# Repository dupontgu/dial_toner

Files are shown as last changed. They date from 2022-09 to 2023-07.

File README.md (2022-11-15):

# The Dial Toner

## An Unnecessary Series of Hardware Color Pickers

### The Dial Toner (Basic)

- The original. [Available on Etsy!](https://www.etsy.com/listing/1327220837/the-dial-toner-a-tactile-mechanical)
- Find usage instructions [here](/basic).
- Dial in your color using the delightfully tactile hex switches.
- Built-in RGB LED's show the (approximate!) color you have selected in real time.
- Smash the button to send the color into your design software (or anywhere, the device acts as a keyboard).
- Can be configured to output Hex, RGB, CMYK, or HSL color.

#### Rev02 

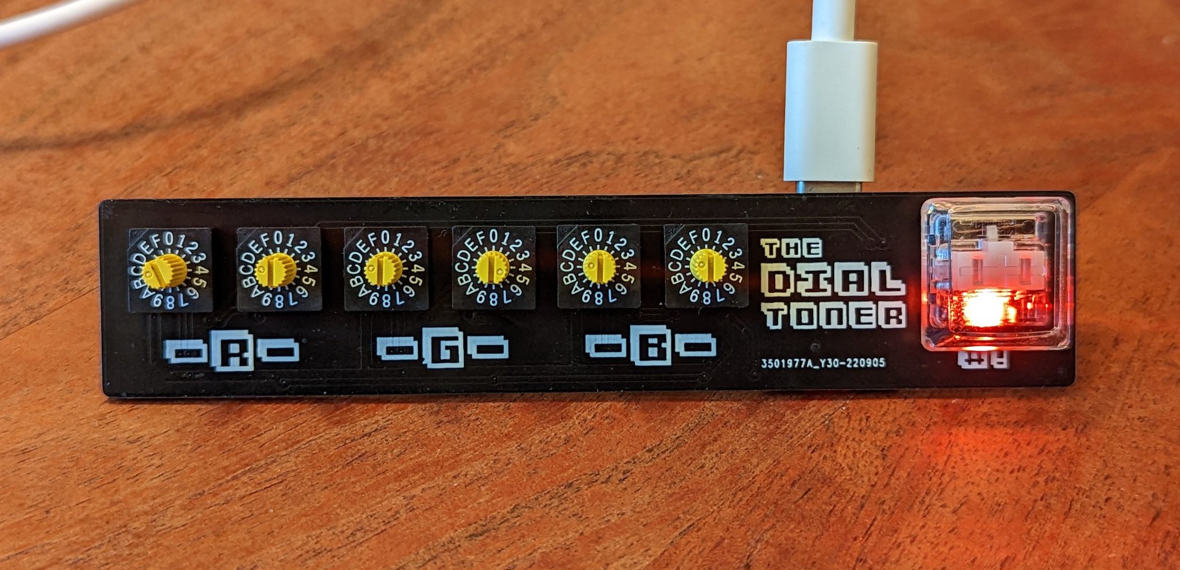
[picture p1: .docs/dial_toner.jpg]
Dial Toner Rev02 Board


----------

### The Dial Toner Ultra

- The "Swiss-army-knife".
- Find usage instructions [here](/ultra).
- Dial in your color using 4 analog dials. Input modes include Hex, RGB, CMYK, HSL, and P**tone.
- 1.3" LCD screen displays your color (and corresponding values) in real time.
- RGB backlit knobs because why not.
- Smash the button to send the color into your design software (or anywhere, the device acts as a keyboard).
- Can be configured to output Hex, RGB, CMYK, or HSL.

#### Rev01

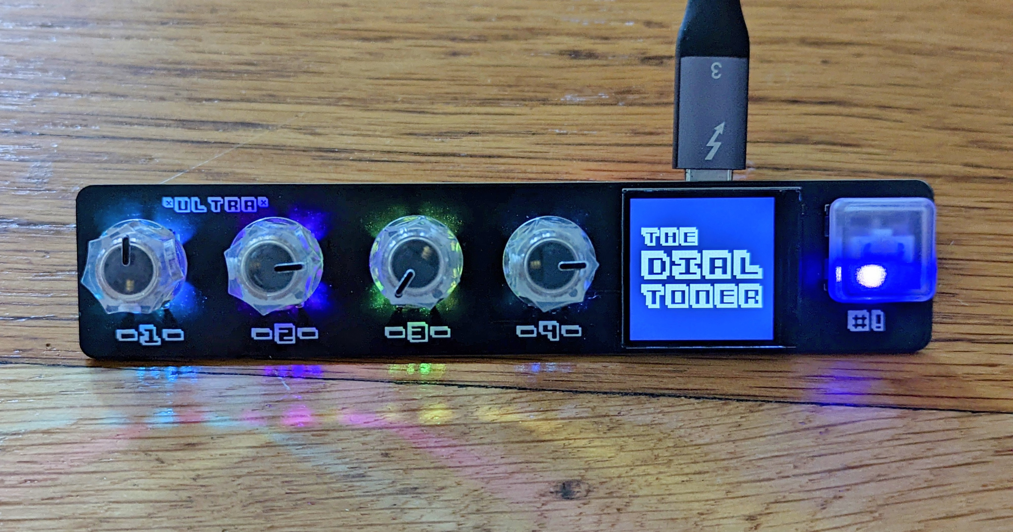
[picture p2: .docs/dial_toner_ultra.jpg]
Dial Toner Ultra Rev01 Board


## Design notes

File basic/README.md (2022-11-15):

# The Dial Toner (Basic)

Dial Toner Rev02 Board

## General Usage
1. Connect the Dial Toner to your computer via USB.
2. Dial in a hex color using the 6 knobs. (Note - the engraved line on top of the knob points to the selected value. There is a small circuilar impression on the _left_ sign of the line.)
3. Observe that the color of the LED (roughly) matches the color you have chosen.
4. Hit the button, and observe that the dial toner types your hex code (followed by a simulated enter key press).

## Changing Configuration
1. Unplug the device.
2. Hold down the “#!” button, and plug the device back in (keep holding!).
3. Hold until you see the LED come on - if it is fading through different colors, the device is in "config" mode. You can release the button.
4. In config mode, each of the knobs corresponds to a config parameter. When you change any of them the light will start to blink, indicating that a change has been made. Hit the button again to save your selection and resume normal operation.
    
    1. **The first knob changes the color output mode**. The possible values are 0 for a hex color string, 1 for RGB (integers, 0-255), 2 for CMYK percentages (decimals), 3 for HSL percentages (decimals). Any other value defaults to hex.

    1. **The second knob changes the "whitespace" mode**. The possible values are 0 for "space" (will insert a space between each discrete value), 1 for "tabs" (will insert a tab between each discrete value, 2 for "comma" (will insert "," between...). Any other value defaults to "space". Tabs are particularly useful when you want to fill multiple input fields in one go. Note - this setting does not affect hex color strings. 

    1. **The third knob sets whether or not to hit a simulated "enter" key after the color value is typed**. 0 will not append enter, 1 will append enter. Any other value defaults to 1 (append enter).

    1. **The fourth knob dials in LED brightness**. 0-F on the knob dials in the brightness percentage from ~0-80% (anything brighter is a bit much). Keep in mind - if you turn the brightness to 0, you will not see the light anymore! Probably a stupid feature, but somebody suggested that it might be fun to play a game where you pick a color and see how close you can dial it in without seeing it. 

    1. **The fifth knob changes the keyboard layout**. The possible values are 0 for United States English, 1 for British English (switches '#' and '£'), and 2 for "International" (should work for most other layouts). Any other selected value defaults to "US".

## Changing/Updating the Firmware:
- This device runs [CircuitPython](https://circuitpython.org/). It’s a really great way to get started with embedded software development. All of the code that powers this device is available on the device for you to play around with. 

- To change/update/check the firmware, you should boot up the device in Debug mode:
    1. Unplug the device
    2. Hold down the button, and plug the device back in (keep holding!).
    3. Wait until you see the LED come on and start cycling through colors (keep holding!).
    4. Unplug the device again.
    5. Keep holding the button down, plug in the device again.
    6. When the LED comes back on, the device should be in normal usage mode, but the storage drive should now be enabled! There should be a drive called CIRCUITPY mounted on your computer.

- To see which version of the firmware you are running, boot up in debug mode (described above), and check the file called `version.txt` on the CIRCUITPY drive. If there is no `version.txt` file, you are likely running version 0.0.1.

- "Official" firmware releases can be found [here](https://github.com/dupontgu/dial_toner/releases/). Find the latest release, and follow the link to the release's artifacts. Download the `DT Basic Bundle` zip file. Extract all of the files from the zip archive and copy them onto the CIRCUITPY drive. **Replace all existing files**. Once copying has finished the device will reboot and will be running the updated code.

- If you want the device to stay in Debug mode, so the files are available every time you reboot (without holding the button down):
    1. Boot the device in Debug mode as described above.
    1. Locate the file called ‘boot.py’ on the CIRCUITPY drive.
    1. Open it in a text editor. (If you don’t have a coding-oriented text editor installed, use something lightweight like TextEdit or Notepad. It’s best not to use a document editor like Microsoft Word)
    1. Change the line that says “DEBUG = False” to say “DEBUG = True”.
    1. Save the boot.py file.
    1. Reboot the device - it should stay in Debug mode as long as “DEBUG = True”.

- You can [change the name](https://learn.adafruit.com/welcome-to-circuitpython/renaming-circuitpy) of the `CIRCUITPY` drive if you want to.

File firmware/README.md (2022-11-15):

# CircuitPython firmware for The Dial Toner
- **This directory contains the code for all models of The Dial Toner**. Shared code lives in the [common](./circuitpython/common/) directory. Other directories contain hardware model-specific code. The [`bundle`](./circuitpython/bundle.py) script will create bundles for each model. The contents of each bundle can be loaded onto the corresponding device wholesale - all existing files should be overwritten. The bundle script also pulls in the necessary dependencies from Adafruit's CircuitPython library bundle.
- All code is currently written for CircuitPython 7. It has been tested on most 7.x releases since 7.2.5.
- All Dial Toner models are currently built around the [Seeeduino XIAO RP2040](https://www.seeedstudio.com/XIAO-RP2040-v1-0-p-5026.html) development board.

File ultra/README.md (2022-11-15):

# The Dial Toner (Ultra)

Dial Toner Ultra Rev01 Board

## General Usage
1. Connect the Dial Toner to your computer via USB.
2. Dial in a color using the 4 knobs. (Each knob will change a different characteristic of the color, depending on which input mode is currently selected. Only knobs with backlights on are active)
3. The text on the LCD screen will display the color's characteristics as you turn the knobs, and the background of the LCD will display the currently selected color.
4. Press and release the button, and observe that the Dial Toner types the selected color value on your computer.

------------

## Changing Configuration
1. To enter config mode, hold the button down for approxmiately 3 seconds. The lights on the board will start to blink once you are in config mode.
2. Once in config mode, the first two knobs can be used to change your settings. The first knob selects the config parameter to be changed. The second knob changes the value of the currently selected parameter.

### Config Parameters

1. **Input Mode, aka `MODE`** - Selects the input mode (colorspace) of the Dial Toner. This determines what each of the knobs does during normal operation.

    **Possible Values:**

    1. `HEX` - The knobs will be used to dial in a hexadecimal, 24-bit RGB color value. Knob 1 will adjust the `red` component, knob 2 will adjust the `green` component, knob 3 will adjust the `blue` component, and knob 4 will be inactive. Each component will be a discrete value between 0x00 and 0xFF. 

    1. `RGB` - The knobs will be used to dial in a 24-bit RGB color value. Knob 1 will adjust the `red` component, knob 2 will adjust the `green` component, knob 3 will adjust the `blue` component, and knob 4 will be inactive. Each component will be a discrete value between 0 and 255. (This is effectively the same as `HEX` mode - only the display is different).

    1. `CMYK` - The knobs will be used to dial in a CMYK color value. Knob 1 will adjust the `cyan` component, knob 2 will adjust the `magenta` component, knob 3 will adjust the `yellow` component, and knob 4 will adjust the `key` component. Each component will be a percentage between 0.0% and 100.0%.

    1. `P-TONE` - The knobs will be used to select a color ID from a certain, well-known ["color matching system"](https://www.pantone-colours.com/). Rhymes with schman-tone. Knob 1 will choose the thousand's digit (0,xxx - 9,xxx) of the ID, knob 2 will choose the hundred's digit (x,0xx - x,9xx), knob 3 will choose the tens's digit (x,x0x - x,x9x), and knob 4 will choose the one's digit (x,xx0, x,xx9). Note that not every number between 0-9999 is present, so the values might jump around a bit. 

    1. `HSL` - The knobs will be used to dial in n HSL. Knob 1 will adjust the `hue` component, knob 2 will adjust the `saturation` component, knob 3 will adjust the `lightness` component, and knob 4 will be inactive. The `hue` value will be an integer between 0 and 359. The `lightness` and `saturation` values will be percentages between 0.0% and 100%.

1. **Button LED Brightness, aka `BTN BRT`** - Adjusts the brightness of the RGB LEDs beneath the button and behind the board. Values are between 0% and 90%. Note that if you choose 0%, the LEDs will be off.

1. **Output Mode, aka `OUTPUT`** - Selects the output mode of the Dial Toner. This determines how the color will be typed out when you hit the button.

    **Possible Values:**

    1. `HEX` - The selected color will be typed out as a 6-digit hexadecimal RGB color, preceded by a `#` symbol. 
    For example: ```#FF4400```

    1. `RGB` - The selected color will be typed out as 3 discrete 8-bit integers. One for `red`, one for `green`, and one for `blue`. They will be separated by commas. 
    For example: ```255, 127, 0```

    1. `CMYK` - The selected color will be typed out as 4 floating point values between 0.0 and 1.0. The first for the `cyan` component, the second for `magenta`, the third for `yellow`, and the fourth for `key`. They will be separated by commas. 
    For example: ```0.334, 1.0, 0.5789229, 0.0```

    1. `HSL` - The selected color will be typed as 3 numbers: an integer (0-359) representing the `hue` component of the color, a floating point percentage value (0.0-1.0) representing the `saturation` level of the color, and another percentage representing the `lightness` of the color. They will be separated by commas.
    For example: ```255, 0.444, 1.0```

1. **Keyboard Layout aka `KEYBRD`** - Selects the regional keyboard layout that the Dial Toner will adhere to. It should match the keyboard layout that your computer is expecting. It ensures that the `#` key is typed correctly when the output mode is set to the `HEX`. The values are `US` for United States English, `UK` for British English, and `INTL` for everything else. (Forgive me for reducing everyone else to "international", but it seems like most other layouts treat the `#` the same way.)

1. **Append Key aka `APPEND`** - Determines whether or not the Dial Toner should append a key press when it is finished typing out a color value. Values are `ENTER` for a simulated `enter` (return) key press, and `NONE` for no additional key presses. Selecting `ENTER` might come in handy if you want to automatically _confirm_ a color selection in whatever software you're using.

---------

## Changing/Updating the Firmware:
- This device runs [CircuitPython](https://circuitpython.org/). It’s a really great way to get started with embedded software development. All of the code that powers this device is available on the device for you to play around with. 

- To change/update/check the firmware, you should boot up the device in Debug mode:
    1. Unplug the device
    2. Hold down the button, and plug the device back in (keep holding!).
    3. Wait until you see the LED come on and start cycling through colors (keep holding!).
    4. Unplug the device again.
    5. Keep holding the button down, plug in the device again.
    6. When the LED comes back on, the device should be in normal usage mode, but the storage drive should now be enabled! There should be a drive called CIRCUITPY mounted on your computer.

- To see which version of the firmware you are running, boot up in debug mode (described above), and check the file called `version.txt` on the CIRCUITPY drive. If there is no `version.txt` file, you are likely running version 0.0.1.

- "Official" firmware releases can be found [here](https://github.com/dupontgu/dial_toner/releases/). Find the latest release, and follow the link to the release's artifacts. Download the `DT Ultra Bundle` zip file. Extract all of the files from the zip archive and copy them onto the CIRCUITPY drive. **Replace all existing files**. Once copying has finished the device will reboot and will be running the updated code.

- If you want the device to stay in Debug mode, so the files are available every time you reboot (without holding the button down):
    1. Boot the device in Debug mode as described above.
    1. Locate the file called ‘boot.py’ on the CIRCUITPY drive.
    1. Open it in a text editor. (If you don’t have a coding-oriented text editor installed, use something lightweight like TextEdit or Notepad. It’s best not to use a document editor like Microsoft Word)
    1. Change the line that says “DEBUG = False” to say “DEBUG = True”.
    1. Save the boot.py file.
    1. Reboot the device - it should stay in Debug mode as long as “DEBUG = True”.

- You can [change the name](https://learn.adafruit.com/welcome-to-circuitpython/renaming-circuitpy) of the `CIRCUITPY` drive if you want to.

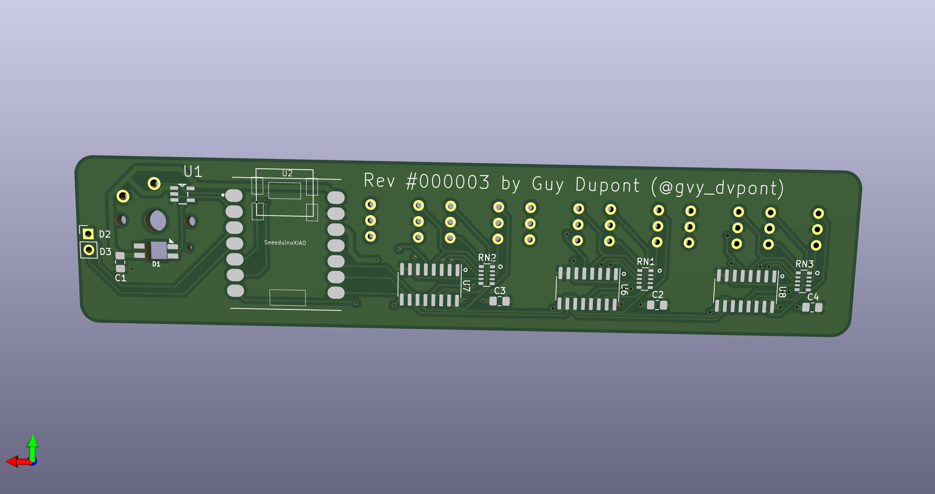
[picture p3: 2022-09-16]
hardware/rev03/dial_toner_mx_v2_back.jpg

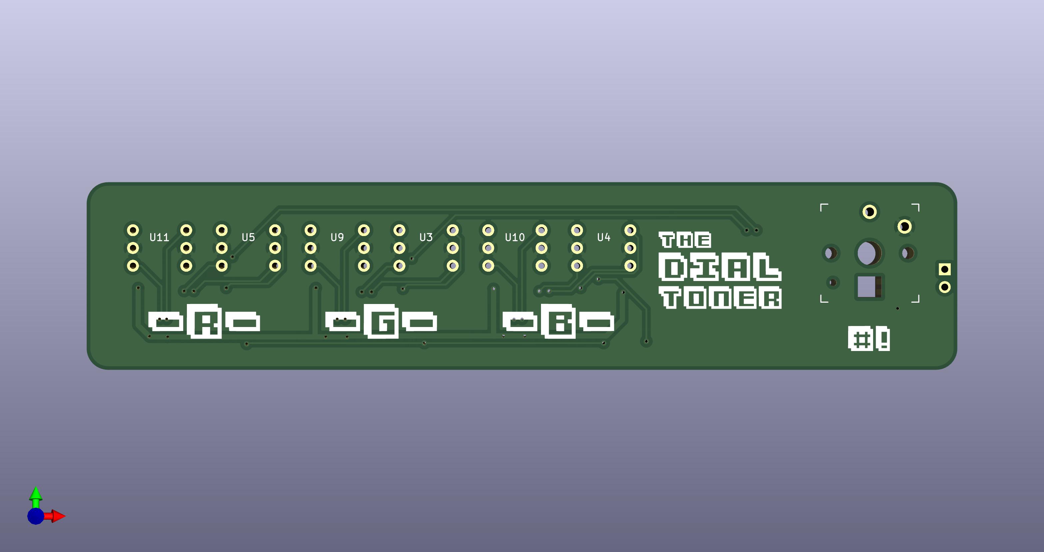
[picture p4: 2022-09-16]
hardware/rev03/dial_toner_mx_v2_front.jpg

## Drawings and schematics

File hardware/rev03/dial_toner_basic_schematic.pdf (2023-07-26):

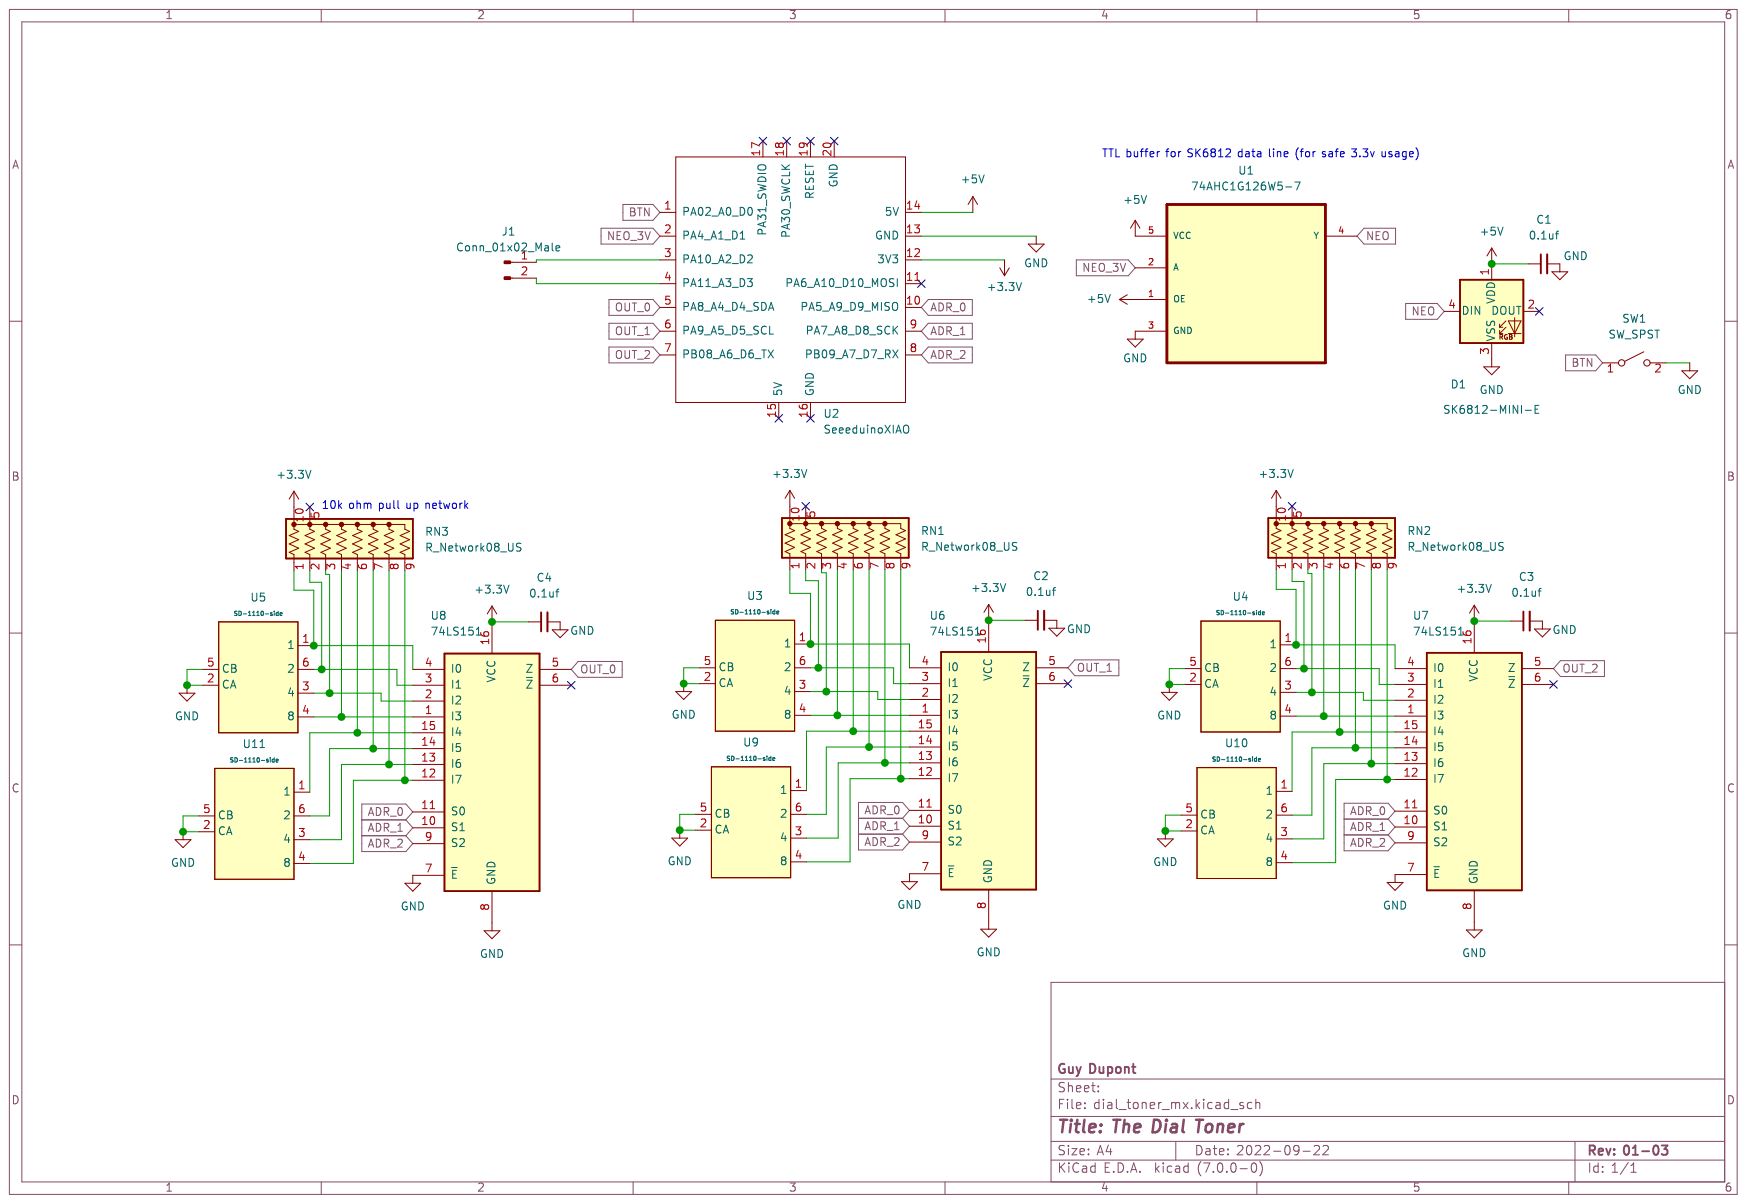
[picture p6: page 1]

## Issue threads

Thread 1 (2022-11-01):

Non-US keyboard - pound / hash symbol (#)

andypiper, 2022-11-01:
I'm using a v3 Dial Toner connected to macOS Ventura.

When I hit the button in the default hex mode, I'm getting (for example) `£E4512A` <- generated directly from the key pad right now.

The `£` symbol should be a `#` symbol 🙂

I'm not 100% sure how to fix this in the code.

On my keyboard, pressing the 3 key with Shift -> `£` and with Alt -> `#`
Nevertheless I was kind of surprised that directly sending the string `#E4512A` (generated via `config.py`) is getting converted to `£E4512A`

- looked into the `KeyboardLayout` for CircuitPython, but I'm not finding (for example) a British English option. It looks like (?) the `KeyboardLayout` assumes specific key locations? Should I add a UK English layout in
- looked at ways to send a `POUND` keycode (considered removing `#` from `hex_sequence` in `config.py` and having the symbol inserted in `dt_keyboard.py` or, having `dt_keyboard.py` do some kind of filtering to replace `#` in `str` if it is passed in).
- basically I've tried a number of things but seem to be struggling to figure out the "best" way to get the actual `#` character sent to the computer.

It might be nice if this could somehow be a config option on the 5th dial or something, but a code change for the end-user is also OK...

dupontgu, 2022-11-01:
Hi Andy, thanks for reporting and looking into it! I can't believe I fell into this trap again, I had a similar issue on my T9 project when I went to intro multiple languages.

Did you have any luck with your second approach? Since there are really no other language-specific components to this project. Would be great if it could just be universal. From a _product_ standpoint, that would be the best option in my opinion.

If not, then yeah - A British English `KeyboardLayout` would be the way to go. I can look into that if you haven't already gotten started. And I like the 5th dial config idea, though it doesn't scale particularly well. Probably not a problem given the scale of this operation. At the very least, I'll rewrite the code to autodetect a custom `KeyboardLayout` file on the CircuitPython drive so no code needs to be altered by the user.

andypiper, 2022-11-01:
Totally recognise that it's a niche/edge case related to internationalisation, so the settings doesn't scale brilliantly.

So I tried a few approaches, either `POUND` or something like

```
keyboard.press(Keycode.LEFT_ALT)
keyboard.press(Keycode.KEYPAD_THREE)
keyboard.press(Keycode.KEYPAD_FIVE)
keyboard.release_all()
```

... right before the `keyboard_layout.send()` but get nothing out at all from the button, until I revert to your code (and I don't see a way to see any error output - I'm typically more of a MicroPython person though). I might have another go at this at the weekend but not immediately able to play further.

Lovely little device, thanks! 👍🏻

dupontgu, 2022-11-01:
Ok - I'm having luck with:
```
self.keyboard.press(Keycode.LEFT_ALT)
self.keyboard.press(Keycode.THREE) #Note - not the KEYPAD_THREE, apparently there's a difference
time.sleep(.02)
self.keyboard.release_all()
```
on a Mac, set to British input source.

I think I'm going to do the 5th dial config idea with 3 different modes:
1. US (as written now, just use the "#ffffff" string as-is)
2. UK (Keycode.LEFT_ALT + THREE, then string)
3. INTL (POUND, then string)

^ seems like a few other languages use POUND for #, so that'll be a catchall for now.

--------

I'm conveniently readying a release right now as I prepare to release the "Ultra" version of the dial toner. There weren't going to be any new features for the v3 Dial Toner but this will make it's way in! I will post back here when I have a release candidate of the CircuitPython bundle.

dupontgu, 2022-11-02:
@andypiper if you want to give the updated code a test, I would greatly appreciate it. The `DT Basic Bundle` for the latest is available here: https://github.com/dupontgu/dial_toner/actions/runs/3381251966

Quite a few internal changes, so I would just overwrite all the files you have.
The `keyboard_mode` parameter is on the 5th knob when you go into config mode.

0 -> US keyboard
1 -> UK
2 -> INTL (everybody else?)
else -> defaults to 0

dupontgu, 2022-11-15:
merged in #2!

Closed 2022-11-15.

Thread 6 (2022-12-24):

Crash when button tapped while computer is asleep

dupontgu, 2022-12-24:
- Gets the CircuitPython "USB is busy" error.
- Observed on macOS Catalina.
- DialToner version 0.2.0

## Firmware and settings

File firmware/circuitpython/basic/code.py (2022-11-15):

import time
from persistence import get_reboot_button_count, read_config, set_reboot_button_count, write_config
from pio_button import PioButton
from rainbowio import colorwheel
import hex_input
import board
from dt_keyboard import Keyboard
from led_wrapper import LedWrapper
from color_util import gamma_correction
from config import BRIGHTNESS_VALS

btn = PioButton(board.D0, sample_frequency = 10000)
keyboard = Keyboard()
pixel = LedWrapper()

colorwheel_count =  0

config = read_config()
write_config(config)

# get the latest colorwheel color, move cursor so it's different next time.
def colorwheel_color():
    global colorwheel_count
    colorwheel_count += 0.4
    if colorwheel_count > 255:
        colorwheel_count = 0
    return colorwheel(colorwheel_count)

def read_bytes_as_rgb_int():
    (r, g, b) = hex_input.read_bytes()
    return r << 16 | g << 8 | b

def gamma_corrected_rgb_int(rgb_int):
    r = rgb_int >> 16
    g = (rgb_int >> 8) & 0xFF
    b = rgb_int & 0xFF
    return gamma_correction[r] << 16 | gamma_correction[g] << 8 | gamma_correction[b]

def get_brightness_from_bytes(bytes):
    return round(((bytes[1] & 0x0F) / 16) * 10)

def commit_config_selection(bytes):
    # first knob, first nibble
    config.output_mode = bytes[0] >> 4
    # second knob, second nibble
    config.whitespace_mode = bytes[0] & 0x0F
    # etc
    config.append_key = bytes[1] >> 4
    config.brightness = get_brightness_from_bytes(bytes)
    config.keyboard_mode = bytes[2] >> 4
    write_config(config)
    print(config)

def config_mode_selection_made():
    while True:
        reading = hex_input.read_bytes()
        if btn.newly_pressed():
            return commit_config_selection(reading)
        pixel.fill(colorwheel_color())
        # blink at selected brightness
        computed_brightness = BRIGHTNESS_VALS[get_brightness_from_bytes(reading)]
        pixel.brightness = 0 if int(time.monotonic() * 6) % 2 == 0 else computed_brightness
        pixel.show()
        time.sleep(0.001)

# blocks until user exits config mode
def config_mode():
    pixel.brightness = config.brightness
    starting_bytes = hex_input.read_bytes()
    while True:
        reading = hex_input.read_bytes()
        btn_press = btn.newly_pressed()
        if reading != starting_bytes:
            return config_mode_selection_made()
        elif btn_press:
            return None
        # slow pulse
        pixel.fill(colorwheel_color())
        pixel.show()
        time.sleep(0.001)

if btn.newly_pressed():
    if get_reboot_button_count() == 1:
        # this will block until user exits config mode  
        config_mode()
        set_reboot_button_count(0)

print("config: ", config)

rgb = None

while True:
    new_rgb = read_bytes_as_rgb_int()
    if new_rgb != rgb:
        rgb = new_rgb
        print(hex(rgb))
        pixel.fill(gamma_corrected_rgb_int(rgb))
        pixel.brightness = config.brightness_float
        pixel.show()
    time.sleep(0.01)
    if btn.newly_pressed():
        str_value = config.sequence_for_rgb(rgb)
        print("btn pressed:", rgb, str_value)
        keyboard.write_string(str_value, config.keyboard_mode_obj)

    

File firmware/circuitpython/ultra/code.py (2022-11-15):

from dt_display import DialTonerDisplay
from knobs import any_knob_has_turned_within
from dt_keyboard import Keyboard
from modes import SettingsMode
from dt_leds import set_all_led_brightness, set_led_bg_color, set_knob_leds, DEFAULT_BRIGHTNESS
import board
import time
from persistence import read_config, write_config
from config_params import all_params
from pio_button import PioButton

IDLE_TIME_THRESHOLD = 1200

display = DialTonerDisplay()
keyboard = Keyboard()
button = PioButton(board.D3)
config = read_config()
idle_time = 0

def settings_mode():
    display.hide_logo()
    display.refresh()
    settings_mode = SettingsMode(read_config(), all_params)
    led_color = (100, 100, 100)
    hold_released = False
    while True:
        settings_mode.refresh()
        set_led_bg_color(led_color, settings_mode.config.brightness_float)
        # flash LEDs while in settings mode
        set_all_led_brightness(0 if round(time.monotonic() * 1.5) % 2 == 0 else DEFAULT_BRIGHTNESS)
        for button_status in button.events:
            if not button_status.pressed:
                # make sure we're not reacting to the release from the initial hold that got us into settings mode
                if not hold_released:
                    hold_released = True
                    continue
                # button newly pressed, save config and exit settings mode
                write_config(settings_mode.config)
                set_all_led_brightness(DEFAULT_BRIGHTNESS)
                time.sleep(0.2)
                return
        display.update_with(settings_mode)
        set_knob_leds(settings_mode.knob_led_colors)
        display.refresh()

    
while True:
    for button_status in button.events:
        if button_status.hold_time >= 30 and button_status.pressed:
            settings_mode()
            config = read_config()
        elif button_status.hold_time < 30 and not button_status.pressed:
            str_value = config.sequence_for_rgb(mode.as_rgb)
            print("btn pressed:", mode.as_rgb, str_value)
            keyboard.write_string(str_value, config.keyboard_mode_obj)
    mode = config.input_mode_obj
    mode.refresh()
    actively_turning = any_knob_has_turned_within(3)
    logo_showing = display.logo_showing
    if actively_turning:
        # device was idle, but now user is turning knobs - bring everything back to default brightness
        if idle_time >= IDLE_TIME_THRESHOLD:
            set_all_led_brightness(DEFAULT_BRIGHTNESS)
        idle_time = 0
        if logo_showing:
            display.hide_logo()
        display.update_with(mode)
        set_led_bg_color(mode.as_rgb, config.brightness_float)
    # done turning knobs, go back to displaying logo
    elif not logo_showing and idle_time < IDLE_TIME_THRESHOLD:
        display.show_logo()
    else:
        idle_time += 1
        # device is idle - dim the lights and hide everying from screen to prevent burn in
        if idle_time == IDLE_TIME_THRESHOLD:
            set_all_led_brightness(0.1)
            display.hide_logo()
            display.update_bg_color(0x000)
            display.refresh(force=True)
    set_knob_leds(mode.knob_led_colors)
    display.refresh()

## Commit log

2022-09-16 add initial fw, hw revisions
    [dial_toner_mx-B_Cu.gbl, dial_toner_mx-B_Mask.gbs, dial_toner_mx-B_Paste.gbp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]
2022-10-31 consolidate button implementation between ultra/basic versions
2022-11-02 finish adding keyboard modes to basic board
2022-11-05 artificually expand ADC range to ensure consistent beginning/end
2022-11-05 hook up led brightness, built-in xiao led
2022-11-05 add idle timeout to dim screen and leds
2023-07-26 Add files via upload
    add dial toner basic schematic
